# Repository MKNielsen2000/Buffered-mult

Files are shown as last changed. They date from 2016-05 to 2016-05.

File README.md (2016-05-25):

# Buffered-mult
A simple, compact 2 x 1:3 / 1 x 1:6 buffered multiple for eurorack utilising high quality OPA4171/OPA2171 opamps for suave sound performance and 1206 components to make it easy for anyone to solder.

This circuit is inspired by [Mutable Instruments LINKS.](http://mutable-instruments.net/modules/links)

###It works like this:

#####1:6 mult
Plug a cable into the IN1 jack to get a signal distributed in a 1:out mult.

#####2 x 1:3 mult
Plug one cable into IN1 and another into IN2/OUT4 and boom, the signal at each of the two inputs is then distributed in 1:3 mults.

Status:

95%
███████▒

Layout done, need to test and verify.

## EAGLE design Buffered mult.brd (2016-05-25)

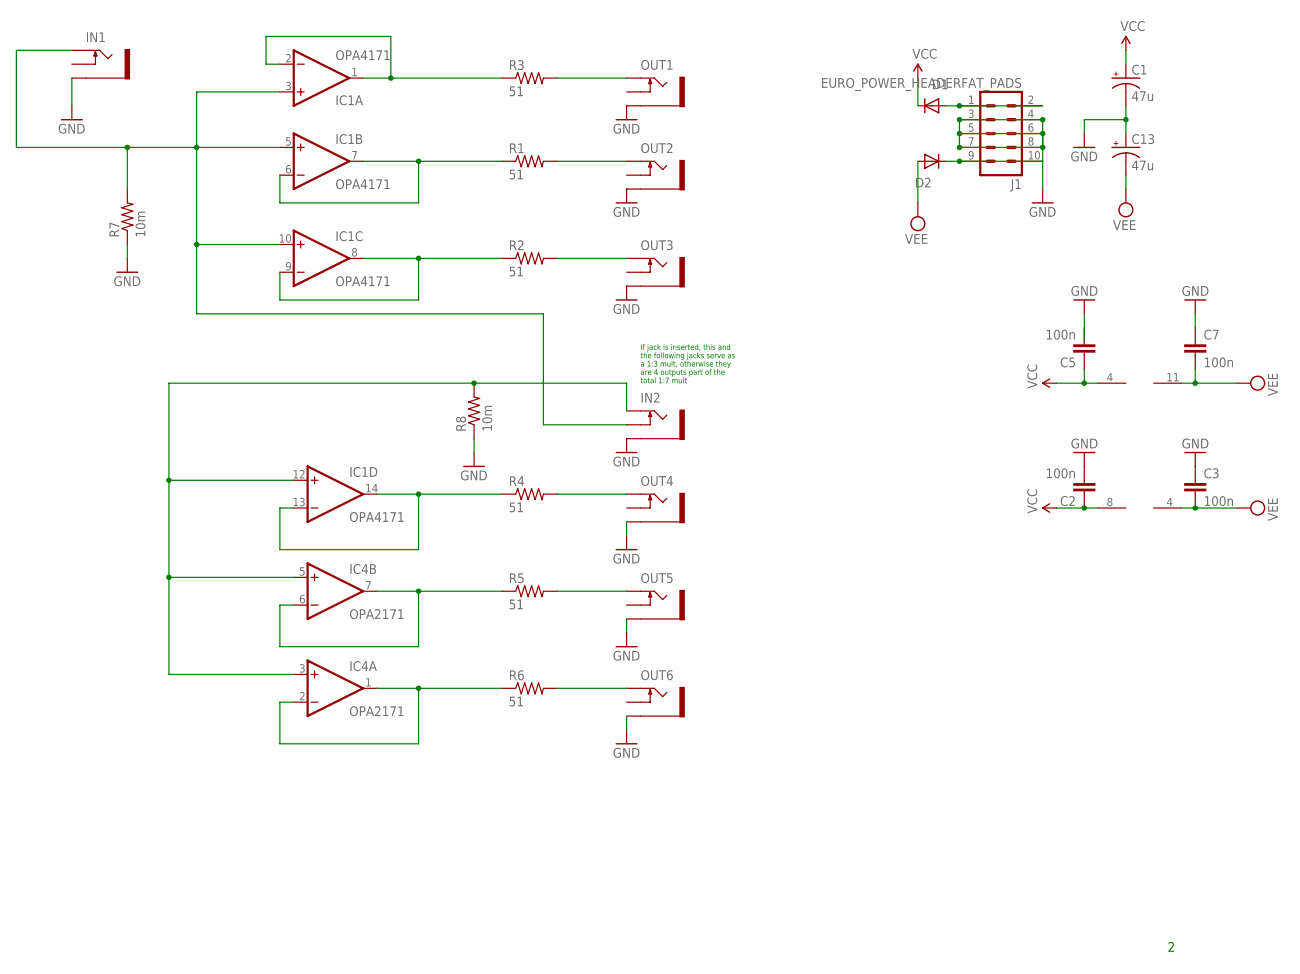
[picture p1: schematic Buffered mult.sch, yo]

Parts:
C1, C13: 47u; PANASONIC_D
C2, C3, C5, C7: 100n; 1206
D1, D2: 1N5819HW; SOD123
IC1: OPA4171; TSSOP14
IC4: OPA2171; SO08
IN1, IN2: PJ302M
J1: EURO_POWER_HEADERFAT_PADS; EURO_PWR_HEADER_FAT
OUT1, OUT2, OUT3, OUT4, OUT5, OUT6: PJ302M
R1, R2, R3, R4, R5, R6: 51; 1206
R7, R8: 10m; 1206

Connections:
GND: C1.-, C2.2, C3.1, C5.2, C7.1, C13.+, IN1.GND (SLEEVE), IN2.GND (SLEEVE), J1.3, J1.4, J1.5, J1.6, J1.7, J1.8, OUT1.GND (SLEEVE), OUT2.GND (SLEEVE), OUT3.GND (SLEEVE), OUT4.GND (SLEEVE), OUT5.GND (SLEEVE), OUT6.GND (SLEEVE), R7.1, R8.1
unnamed: OUT6.TIP, R6.2
unnamed: IC1.1 (OUT), IC1.2 (-IN), R3.1
unnamed: OUT5.TIP, R5.2
unnamed: OUT4.TIP, R4.2
unnamed: IC1.3 (+IN), IC1.5 (+IN), IC1.10 (+IN), IN1.TIP, IN2.SW (SWITCH), R7.2
unnamed: IC1.8 (OUT), IC1.9 (-IN), R2.1
unnamed: OUT2.TIP, R1.2
unnamed: OUT3.TIP, R2.2
unnamed: OUT1.TIP, R3.2
unnamed: IC1.6 (-IN), IC1.7 (OUT), R1.1
unnamed: IC4.1 (OUT), IC4.2 (-IN), R6.1
unnamed: IC4.6 (-IN), IC4.7 (OUT), R5.1
unnamed: D2.C, J1.9, J1.10
unnamed: D1.A, J1.1, J1.2
unnamed: IC1.13 (-IN), IC1.14 (OUT), R4.1
unnamed: IC1.12 (+IN), IC4.3 (+IN), IC4.5 (+IN), IN2.TIP, R8.2
VCC: C1.+, C2.1, C5.1, D1.C, IC1.4 (V+), IC4.8 (V+)
VEE: C3.2, C7.2, C13.-, D2.A, IC1.11 (V-), IC4.4 (V-)

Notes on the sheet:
If jack is inserted, this and the following jacks serve as a 1:3 mult, otherwise they are 4 outputs part of the total 1:7 mult

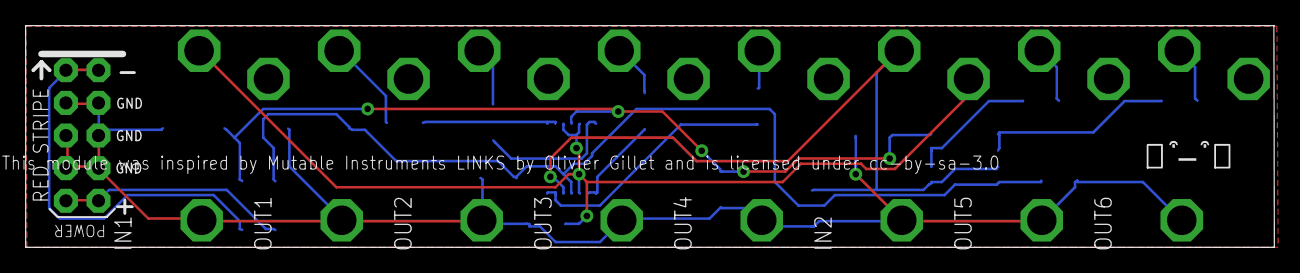
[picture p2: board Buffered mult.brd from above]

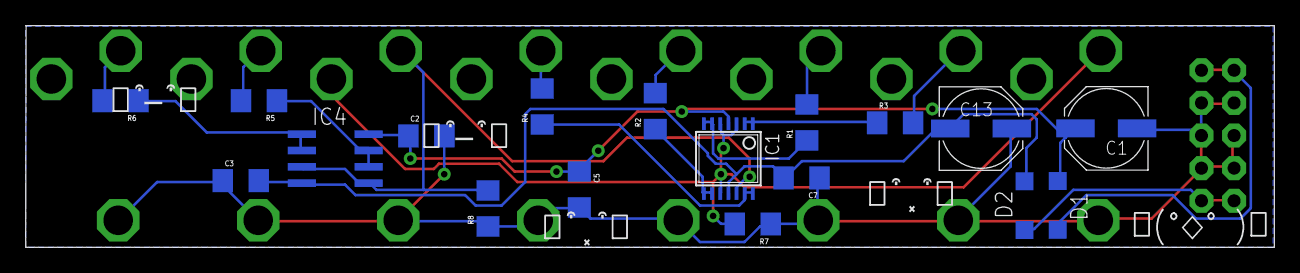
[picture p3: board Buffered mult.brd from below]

Board: 2 copper layers, 97.2 x 17.2 mm, 27 parts (18 on the bottom side), 19 nets.

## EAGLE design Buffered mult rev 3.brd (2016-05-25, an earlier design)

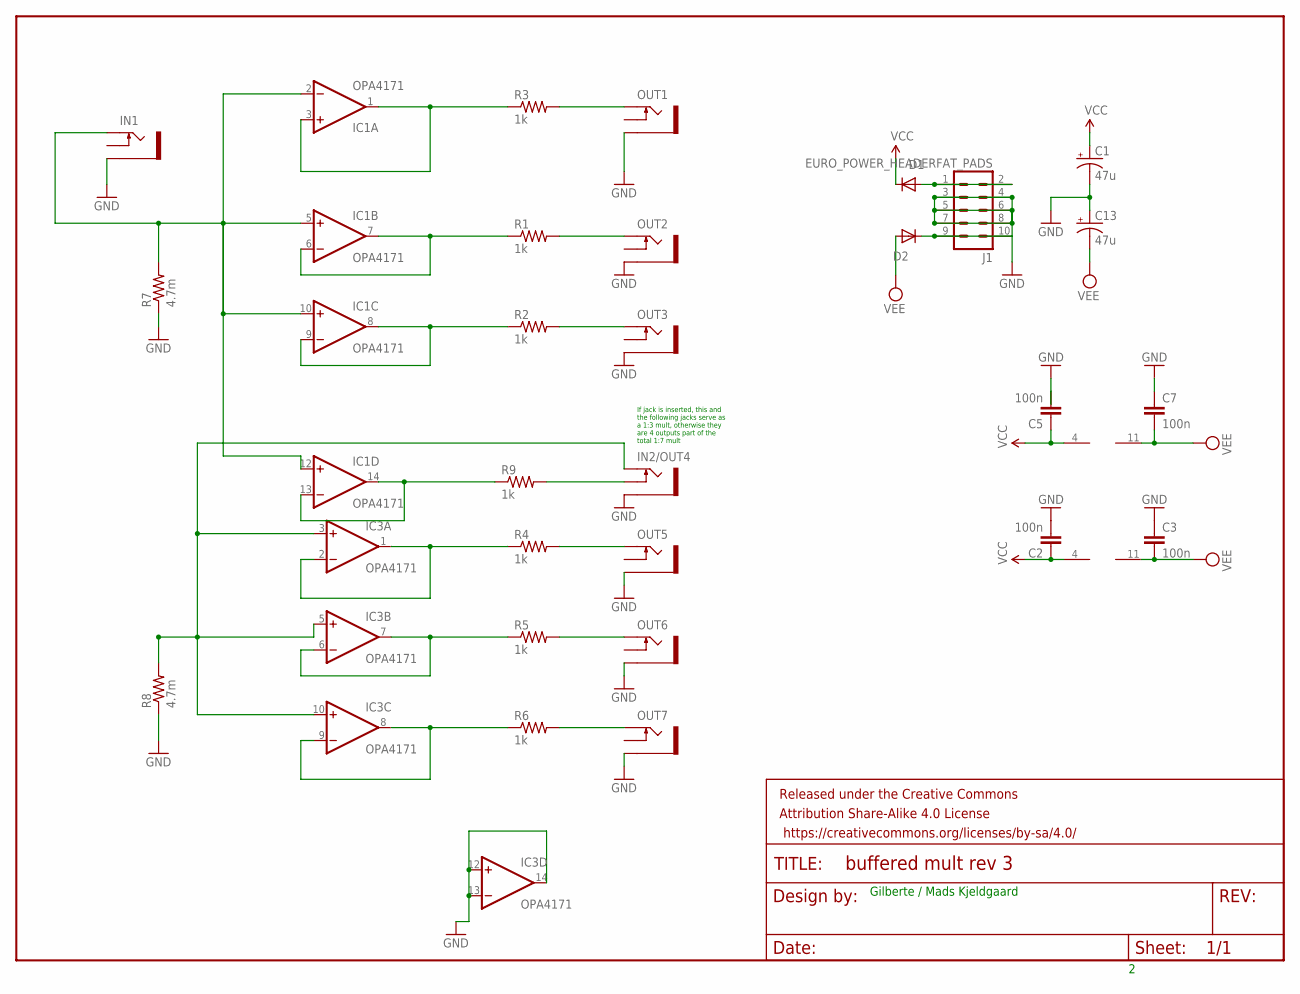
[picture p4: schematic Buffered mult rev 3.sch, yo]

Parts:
C1, C13: 47u; PANASONIC_D
C2, C3, C5, C7: 100n; 1206
D1, D2: 1N5819HW; SOD123
FRAME1: FRAME-LETTER; CREATIVE_COMMONS
IC1, IC3: OPA4171; TSSOP14
IN1, IN2/OUT4: PJ302M
J1: EURO_POWER_HEADERFAT_PADS; EURO_PWR_HEADER_FAT
OUT1, OUT2, OUT3, OUT5, OUT6, OUT7: PJ302M
R1, R2, R3, R4, R5, R6, R9: 1k; 1206
R7, R8: 4.7m; 1206

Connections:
GND: C1.-, C2.2, C3.1, C5.2, C7.1, C13.+, IC3.12 (+IN), IC3.13 (-IN), IC3.14 (OUT), IN1.GND (SLEEVE), IN2/OUT4.GND (SLEEVE), J1.3, J1.4, J1.5, J1.6, J1.7, J1.8, OUT1.GND (SLEEVE), OUT2.GND (SLEEVE), OUT3.GND (SLEEVE), OUT5.GND (SLEEVE), OUT6.GND (SLEEVE), OUT7.GND (SLEEVE), R7.1, R8.1
unnamed: OUT7.TIP, R6.2
unnamed: IC1.1 (OUT), IC1.3 (+IN), R3.1
unnamed: OUT6.TIP, R5.2
unnamed: OUT5.TIP, R4.2
unnamed: IC1.2 (-IN), IC1.5 (+IN), IC1.10 (+IN), IC1.12 (+IN), IN1.TIP, R7.2
unnamed: IC1.8 (OUT), IC1.9 (-IN), R2.1
unnamed: OUT2.TIP, R1.2
unnamed: OUT3.TIP, R2.2
unnamed: OUT1.TIP, R3.2
unnamed: IC1.6 (-IN), IC1.7 (OUT), R1.1
unnamed: IC3.8 (OUT), IC3.9 (-IN), R6.1
unnamed: IC3.6 (-IN), IC3.7 (OUT), R5.1
unnamed: D2.C, J1.9, J1.10
unnamed: D1.A, J1.1, J1.2
unnamed: IC1.13 (-IN), IC1.14 (OUT), R9.1
unnamed: IC3.1 (OUT), IC3.2 (-IN), R4.1
unnamed: IN2/OUT4.SW (SWITCH), R9.2
unnamed: IC3.3 (+IN), IC3.5 (+IN), IC3.10 (+IN), IN2/OUT4.TIP, R8.2
VCC: C1.+, C2.1, C5.1, D1.C, IC1.4 (V+), IC3.4 (V+)
VEE: C3.2, C7.2, C13.-, D2.A, IC1.11 (V-), IC3.11 (V-)

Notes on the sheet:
Gilberte / Mads Kjeldgaard
If jack is inserted, this and the following jacks serve as a 1:3 mult, otherwise they are 4 outputs part of the total 1:7 mult

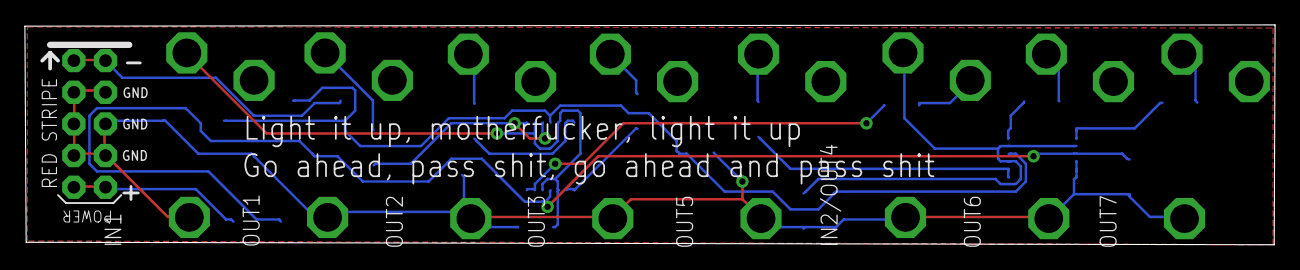
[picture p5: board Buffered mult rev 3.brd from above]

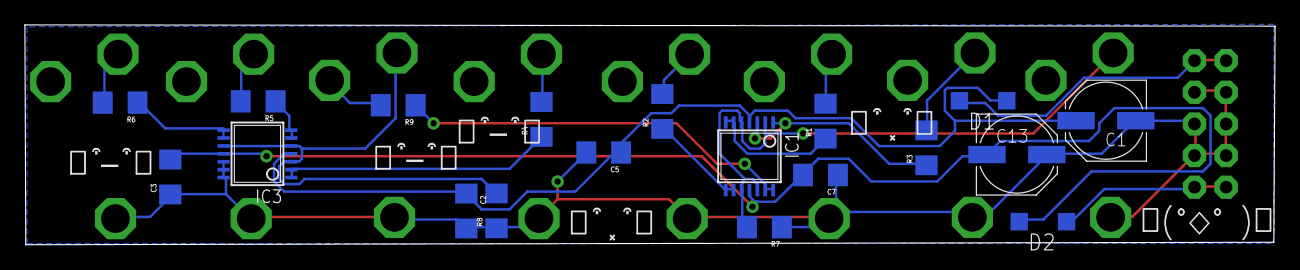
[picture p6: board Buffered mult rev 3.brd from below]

Board: 2 copper layers, 100.4 x 17.6 mm, 29 parts (19 on the bottom side), 21 nets.

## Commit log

2016-05-22 minor adjustments to schem
    [Buffered mult.sch]
2016-05-22 Rev 2 made. Changed opamps to tl072 so they fit between the jack pins
    [Buffered mult rev 1.sch, Buffered mult rev 2.sch]
2016-05-25 Opaxx71 version laid out, optimized pj302m jacks and did a first draft of pcb layout
    [Buffered mult rev 3.brd, Buffered mult rev 3.sch]
2016-05-25 minor changes
    [Buffered mult rev 2.brd, Buffered mult rev 2.sch, Buffered mult rev 3.brd]
2016-05-25 Layout done.
    [Buffered mult rev 1.sch, Buffered mult rev 2.brd, Buffered mult rev 2.sch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]
2016-05-25 Finalized design, generated Gerbers.
    [Buffered mult rev 3.brd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]
2016-05-25 fixed error in schematic
    [Buffered mult.brd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]
2016-05-25 board update
    [Buffered mult.brd]
2016-05-25 new revision: Changed IC2 to opa2171, fixed switch jack
    [Buffered mult.brd, Buffered mult.sch]
2016-05-25 small touchups
    [Buffered mult.brd, Buffered mult.sch]
2016-05-25 last donut of the night
    [Buffered mult.brd]

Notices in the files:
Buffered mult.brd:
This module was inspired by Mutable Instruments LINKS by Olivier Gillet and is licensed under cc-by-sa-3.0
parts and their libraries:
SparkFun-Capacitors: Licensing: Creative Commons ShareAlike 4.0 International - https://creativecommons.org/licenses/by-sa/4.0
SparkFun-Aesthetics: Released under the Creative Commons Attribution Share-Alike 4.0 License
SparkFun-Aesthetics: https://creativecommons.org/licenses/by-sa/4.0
